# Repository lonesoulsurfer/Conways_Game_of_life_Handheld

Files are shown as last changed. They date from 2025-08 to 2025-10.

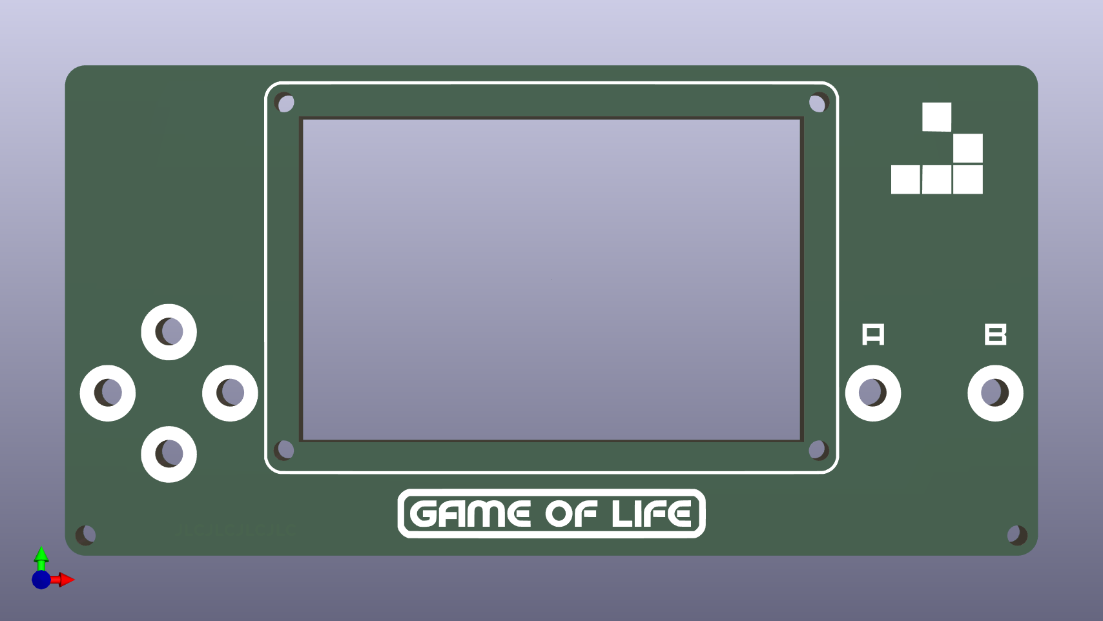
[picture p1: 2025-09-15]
Game of life - Kicad.png

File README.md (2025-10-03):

OOLO0046        QAZB0208

YouTube Vid
Short - https://youtube.com/shorts/Atr1aoWWVLA

Long - https://youtu.be/dLQRpCf72iw

I’ve been fascinated with Conway’s Game of Life ever since I read ‘The Recursive Universe’ way back in 2012. Since then, I wanted a way that I could play the game just like you would play a Nintendo ‘Game & Watch’ – a pocket-sized version that I could whip out anytime and start to explore & build my own patterns.

Fast-forward to 2025 and that idea has become reality! Arduino AI Assistant has been a massive help in building the code and there is absolutely no way that I could of done it without AI’s assistance. If you haven’t used it before and don’t know much about coding, then I strongly recommend that you give it a try.

So, what is Conway’s Game of Life (or GOL for short!). I recently gave the below description in another GOL project which might help those that haven’t heard of it before:

The Game of Life is a cellular automation created by mathematician John Conway. It's what is known as a zero player game, meaning that its evolution and game play is determined by its initial state and requires no further input. You interact with the Game of Life by creating an initial configuration and observing how it evolves.

The game itself is based on a few, simple, mathematical rules consisting of a grid of cells that can either live, die or multiply. When the game is run, the cells can give the illusion that they are alive which is what makes this game so interesting.
Now you know what it is – what does my hand held game version do?

Core Game

• Cellular Automaton: Simulates Conway's famous "zero-player game" where cells live/die based on neighbor count 
• Displayed on a 128x64 OLED screen 
• Toroidal World: Edges wrap around (top connects to bottom, left to right)

5 Game Modes (4 & 5 added in V2)
1. Random Game: Starts with random cell pattern, auto-resets when pattern dies/repeats
2. Custom Builder: Interactive editor to design your own starting patterns
3. Preset Patterns: 5 famous Conway patterns including Gosper Glider Gun
4. Custom Game: Build your own pattern with cursor, long-press SET to start
5. Alt Games: Alternative cellular automata collection
   
     • Brian's Brain: 3-state automaton with birth/dying/dead phases
   
     • Day & Night: Inverse Conway rules creating dense stable patterns
   
     • Seeds: Birth-only automaton creating explosive wave patterns
   
     • Langton's Ant: Single ant creating emergent highway patterns

Controls (5-button resistor ladder)

• Menu Navigation: UP/DOWN navigate, SET selects, LEFT goes back 
• Pattern Editor: Arrow keys move cursor, SET toggles cells, long-press SET starts simulation 
• During Simulation: UP/DOWN changes speed (12 levels), LEFT/RIGHT generates new random

Features

• Real-time Statistics: Generation counter, live cell count, max cells reached 
• Smart Detection: Automatically detects when patterns die out or start repeating 
• Game Over Screen: Shows final statistics for 4 seconds 
• Battery Optimized: Efficient bit-manipulation algorithms 
• Menu System: Clean interface with pattern submenu

Heres some more ideas to implement:

Pattern Management

• Pattern Save/Load: Store custom patterns in EEPROM with names 

• Pattern Library: More famous patterns (pulsar, pentadecathlon, etc.) 

• Random Seeds: Different randomization algorithms (sparse, dense, clusters) 

• Symmetrical Patterns: Generate symmetric starting conditions

Game Modes

• Survival Mode: Try to keep population above threshold for X generations 

• Target Mode: Reach specific cell count goals 

• Time Challenge: Fastest to stabilization 

• Multi-Rule Mode: Different cellular automaton rules (B36/S23, etc.)

Advanced Controls

• Step Mode: Advance one generation at a time with button press 

• Rewind: Store last N generations for backward stepping 

• Pause/Resume: Freeze simulation mid-run 

• Bookmark Positions: Mark interesting generations to return to

Statistics & Analysis

• Population Oscillation Detection: Identify period-N oscillators 

• Stability Analysis: Time to stabilization metrics 

• High Score System: Longest-lived patterns, highest populations 

• Pattern Classification: Auto-detect gliders, oscillators, still lifes

Hardware Enhancements

• Sound Effects: Beeps for births/deaths, musical tones for populations 

 • Color Coding: Different colors for cell age or generation born

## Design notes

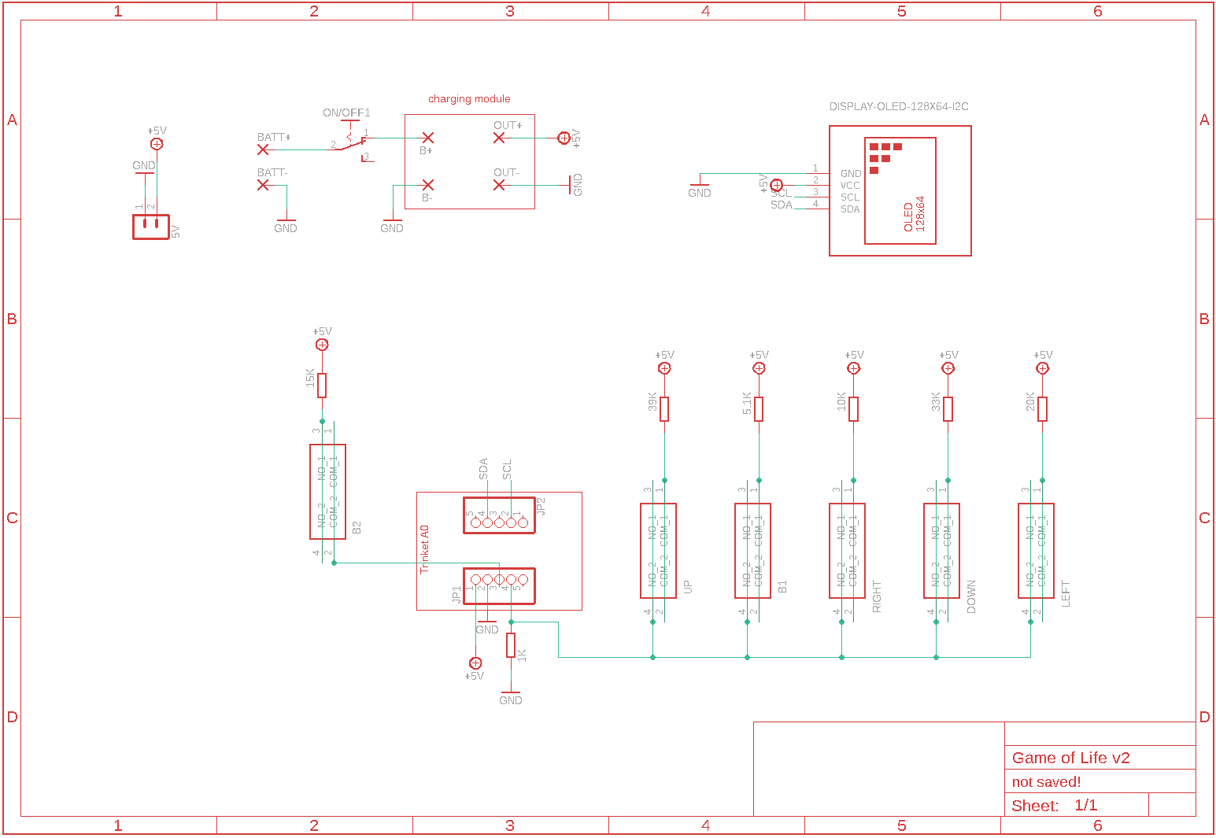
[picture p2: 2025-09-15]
Schematic.png

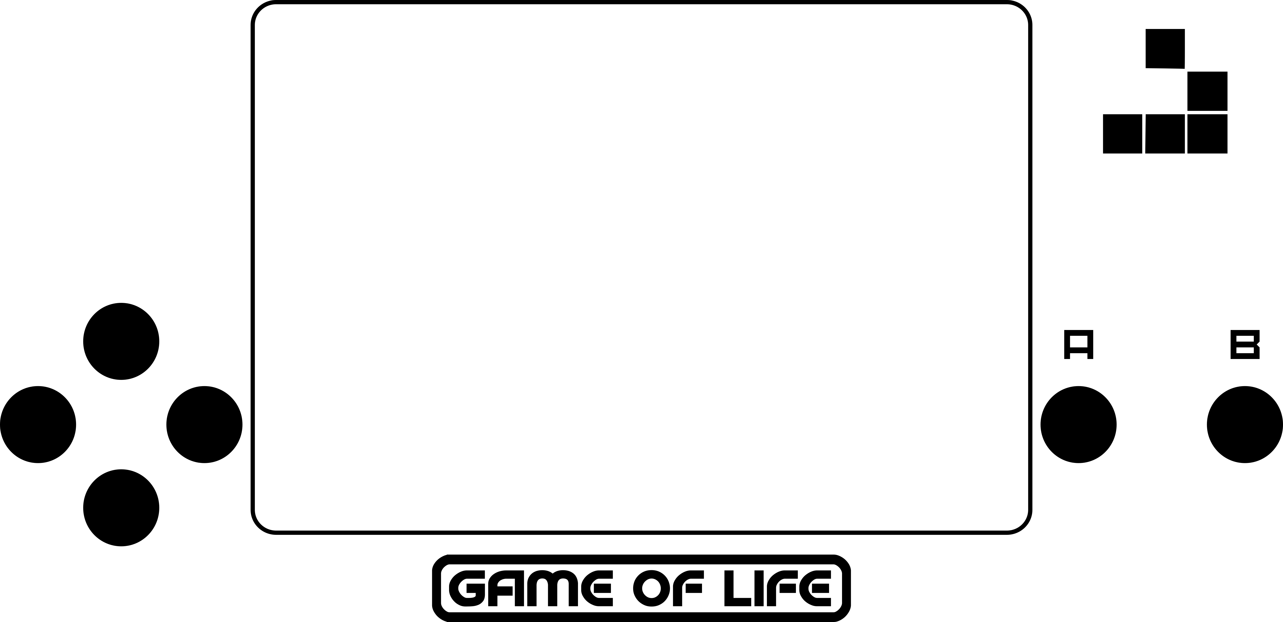
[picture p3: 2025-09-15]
Game of Life - Front Panel Design/Game of Life - Front Panel.png

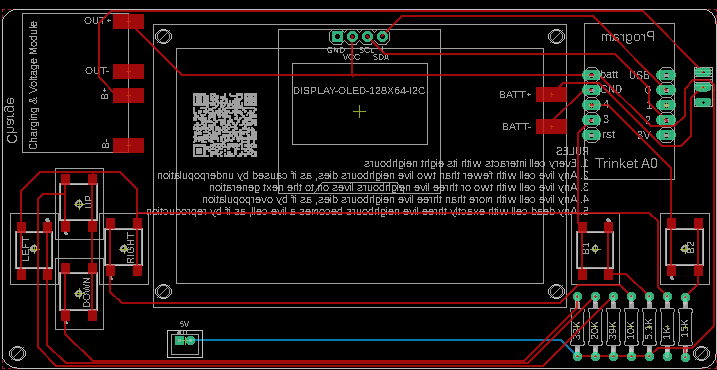
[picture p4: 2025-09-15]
PCB.png

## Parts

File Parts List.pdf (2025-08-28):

Part | Part Number | Type Value | Qty | Link | Image | Notes
Adafruit Trinket M0 | LLC 3500 | 3V version | 1 | Ali Express (https://www.aliexpress.com/w/wholesale-trinket-M0.html?spm=a2g0o.detail.search.0) | | These are availiable from a few different places so check Google for your closest stockist
Charging & voltage step-up module | LX-LCBST | | 1 | Ali Express (https://www.aliexpress.com/item/1005005656423941.html?srcSns=sns_More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)
OLED Screen - 2.42 inch | SSD1309 | | 1 | Ali Express (https://www.aliexpress.com/w/wholesale-oled-2.42.html?spm=a2g0o.detail.search.0)
Resistors | | 1K 5.1K 10K Metal film 15K 20K 33K 39K | 1 1 1 1 1 1 1 | Ali Express (https://www.aliexpress.com/w/wholesale-resistor-metal-film.html?spm=a2g0o.productlist.search.0)
Battery | EB425161LU | Samsung mobile phone battery | | Ali Express (https://www.aliexpress.com/w/wholesale-EB425161LU.html?spm=a2g0o.productlist.search.0)
Tactile Switch | | SMD 11mm | 6 | Ali Express (https://www.aliexpress.com/item/1005007076344493.html?srcSns=sns_More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)
On/Off Switch | MSK-12D19 | Horizontal slide | 1 | Ali Express (https://www.aliexpress.com/item/32828124825.html?srcSns=sns_More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)

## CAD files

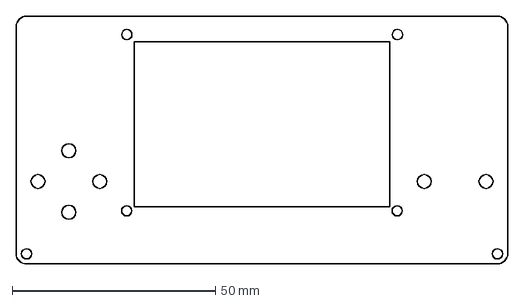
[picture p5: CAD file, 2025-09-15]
Game of Life - Front Panel Design/Game of Life - Fusion.dxf
120.9 x 61.0 mm

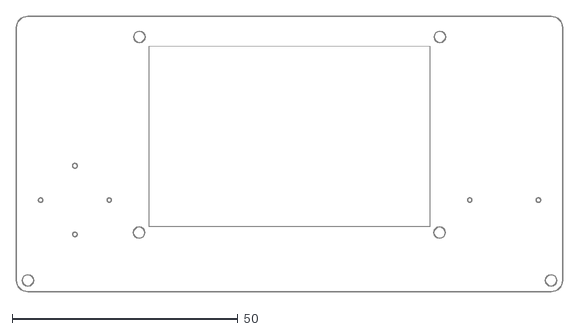
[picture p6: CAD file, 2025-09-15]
Game of Life - Front Panel Design/Game of Life - PCB.dxf
120.9 x 60.9

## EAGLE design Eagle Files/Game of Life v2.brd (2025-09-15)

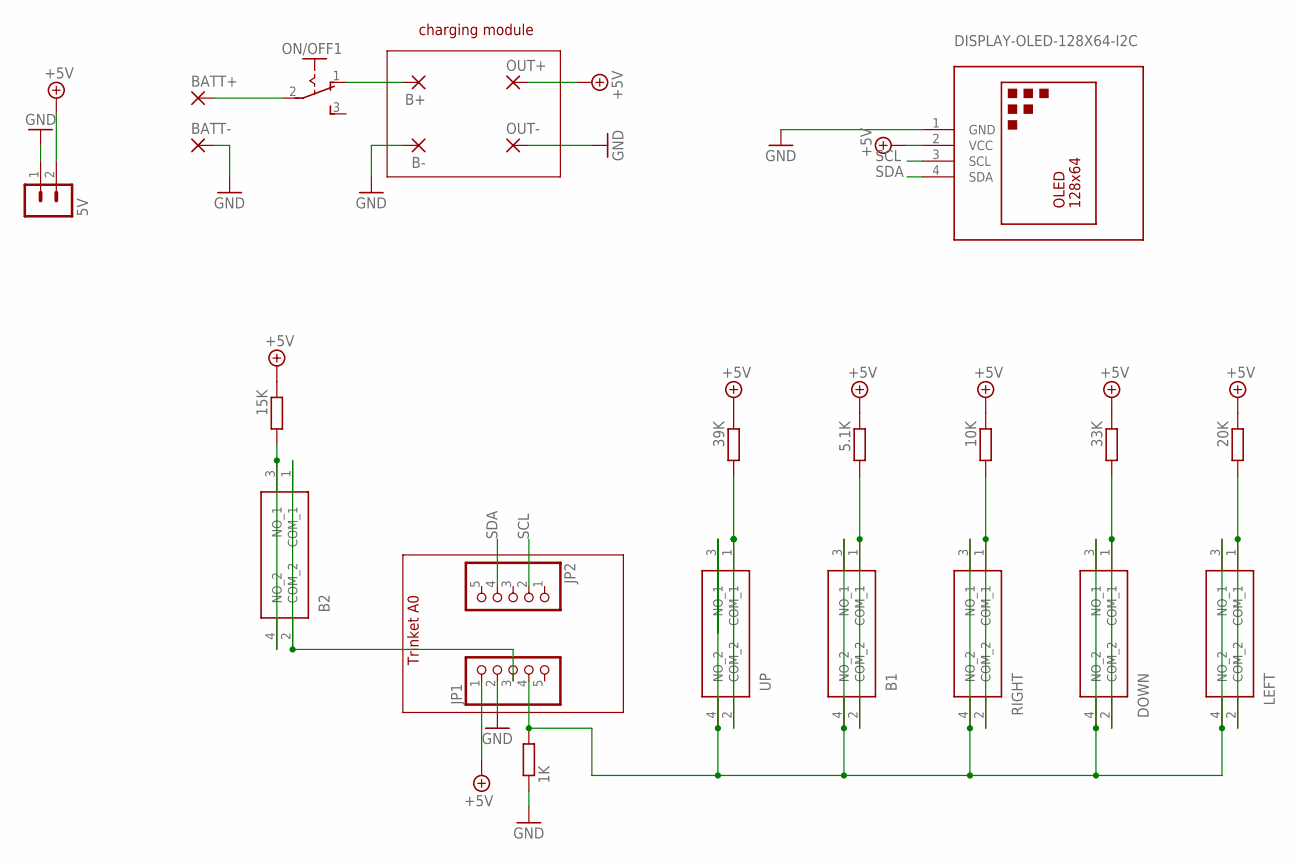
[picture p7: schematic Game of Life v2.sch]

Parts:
5V: B2B-PH-K-S
B1, B2: 101-0364-EV; 1010364EV
B+: SMD5; SMD2,54-5,08
B-: SMD5; SMD2,54-5,08
BATT+: SMD5; SMD2,54-5,08
BATT-: SMD5; SMD2,54-5,08
DOWN: 101-0364-EV; 1010364EV
JP1, JP2: PINHD-1X5; 1X05
LEFT: 101-0364-EV; 1010364EV
ON/OFF1: M251
OUT+: SMD5; SMD2,54-5,08
OUT-: SMD5; SMD2,54-5,08
R1: 1K; 0207/10
R2: 20K; 0207/10
R3: 39K; 0207/10
R4: 10K; 0207/10
R5: 33K; 0207/10
R6: 5.1K; 0207/10
R7: 15K; 0207/10
RIGHT: 101-0364-EV; 1010364EV
U$2: DISPLAY-OLED-128X64-I2C
UP: 101-0364-EV; 1010364EV

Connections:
+5V: 5V.2, JP1.1, OUT+.1, R2.1, R3.1, R4.1, R5.1, R6.1, R7.1, U$2.2 (VCC)
GND: 5V.1, B-.1, BATT-.1, JP1.2, OUT-.1, R1.1, U$2.1 (GND)
unnamed: DOWN.1 (COM_1), DOWN.2 (COM_2), R5.2
unnamed: R3.2, UP.1 (COM_1), UP.2 (COM_2)
unnamed: R4.2, RIGHT.1 (COM_1), RIGHT.2 (COM_2)
unnamed: B1.3 (NO_1), B1.4 (NO_2), DOWN.3 (NO_1), DOWN.4 (NO_2), JP1.4, LEFT.3 (NO_1), LEFT.4 (NO_2), R1.2, RIGHT.3 (NO_1), RIGHT.4 (NO_2), UP.3 (NO_1), UP.4 (NO_2)
unnamed: LEFT.1 (COM_1), LEFT.2 (COM_2), R2.2
unnamed: B1.1 (COM_1), B1.2 (COM_2), R6.2
unnamed: B2.1 (COM_1), B2.2 (COM_2), JP1.3
unnamed: BATT+.1, ON/OFF1.2
unnamed: B+.1, ON/OFF1.1 (O)
unnamed: B2.3 (NO_1), B2.4 (NO_2), R7.2
SCL: JP2.2, U$2.3 (SCL)
SDA: JP2.4, U$2.4 (SDA)

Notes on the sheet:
Trinket A0
charging module

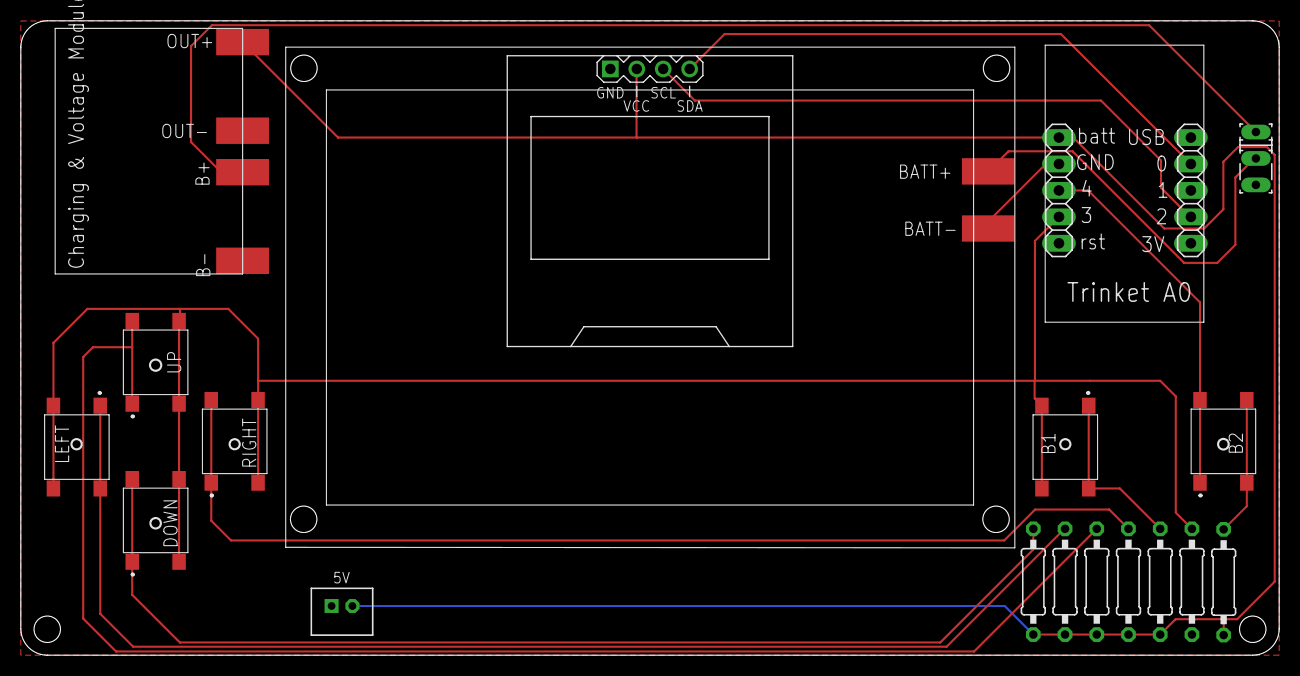
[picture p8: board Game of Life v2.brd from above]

Board: 2 copper layers, 120.9 x 60.9 mm, 24 parts (0 on the bottom side), 14 nets.

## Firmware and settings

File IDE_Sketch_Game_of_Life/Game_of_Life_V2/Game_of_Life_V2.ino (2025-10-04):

/*
 * =====================================================================
 *                    CONWAY'S GAME OF LIFE
 *                     Arduino Implementation
 * =====================================================================
 * 
 * A complete implementation of John Conway's famous cellular automaton
 * "Game of Life" for Arduino microcontrollers with SSD1306 OLED display.
 * 
 * FEATURES:
 * • Five game modes: Random generation, Custom builder, Preset patterns, Symmetric patterns, Alt Games
 * • 12 speed levels with real-time speed control
 * • 5 famous Conway patterns + Symmetric pattern generator
 * • 4 Alternative cellular automata: Brian's Brain, Day & Night, Seeds, Langton's Ant
 * • Interactive pattern editor with blinking cursor
 * • Game statistics tracking (generations, max cells)
 * • Comprehensive menu system with multiple submenus
 * • Automatic pattern detection and game reset
 * • Battery-optimized resistor ladder button input
 * 
 * HARDWARE REQUIREMENTS:
 * • Arduino-compatible microcontroller (tested on Trinket M0)
 * • SSD1306 128x64 OLED display (I2C)
 * • 5-button resistor ladder on analog pin A3
 * • Optional: Button B on analog pin A4 (menu return)
 * 
 * BUTTON MAPPING (Resistor Ladder on A3):
 * • UP: ~39kΩ to 5V    (Navigation/Cursor up/Speed up)
 * • DOWN: ~33kΩ to 5V  (Navigation/Cursor down/Speed down) 
 * • LEFT: ~20kΩ to 5V  (Cursor left/New random/Back in menu)
 * • RIGHT: ~10kΩ to 5V (Cursor right/New random)
 * • SET: ~5.1kΩ to 5V  (Select/Toggle cell/Start simulation)
 * • B: ~15kΩ to 5V   (Return to main menu from anywhere)
 * 
 * GAME MODES:
 * 1. Preset Patterns: Choose from 5 famous Conway patterns
 * 2. Random Game: Starts with random cell pattern, auto-resets on death
 * 3. Symmetric Game: Generate symmetric patterns (Small/Medium/Large)
 * 4. Custom Game: Build your own pattern with cursor, long-press SET to start
 * 5. Alt Games: Alternative cellular automata collection
 *    • Brian's Brain: 3-state automaton with birth/dying/dead phases
 *    • Day & Night: Inverse Conway rules creating dense stable patterns
 *    • Seeds: Birth-only automaton creating explosive wave patterns
 *    • Langton's Ant: Single ant creating emergent highway patterns
 * 
 * CONTROLS:
 * • Menu: UP/DOWN navigate, SET selects, LEFT goes back in submenu
 * • Edit: Arrow keys move cursor, SET toggles cell, long-press SET starts
 * • Simulation: UP/DOWN changes speed, LEFT/RIGHT generates new random
 * • Any mode: Button B returns to main menu
 * • SYMMETRIC PATTERNS: 3 symmetry types (Vertical, Horizontal, 4-way Rotational)
 * 
 * DISPLAY:
 * • 64x32 cell grid displayed at 2x scale on 128x64 OLED
 * • Real-time generation counter and cell statistics
 * • Blinking cursor in edit mode
 * • Automatic game over detection and statistics display
 * • Game-specific visual indicators (ant position, dying cells, etc.)
 * 
 * ALGORITHM:
 * • Optimized bit-manipulation implementation
 * • Toroidal (wraparound) boundary conditions
 * • Hash-based pattern repetition detection
 * • Efficient neighbor counting using lookup table
 * • Game-specific rule engines for each cellular automaton
 * 
 * AUTHOR: Marcus Dunn
 * VERSION: 2.0
 * DATE: 25/09/2025
 * LICENSE: Open Source - feel free to modify and share
 * 
 * Based on John Conway's "Game of Life" cellular automaton (1970)
 * Additional automata: Brian's Brain (1984), Day & Night, Seeds, Langton's Ant (1986)
 * 
 * =====================================================================
 */

#pragma message (" game_of_life_V2 " 25/9/2025 " ")
#include <stdint.h>
#include <limits.h>
#include <stdlib.h>

#include <Wire.h>
#include <Adafruit_GFX.h>
#include <Adafruit_SSD1306.h>

// --- Constants ---
#define SCREEN_WIDTH 128
#define SCREEN_HEIGHT 64

#define BOARD_WIDTH 64
#define BOARD_HEIGHT 32

#define SCALE 2

#define I2C_ADDR 0x3C

// how often to take a hash
#define SHORT_HASH_INTERVAL 6
#define LONG_HASH_INTERVAL 256

// fraction of 32767 to randomly reset if long hash matches
#define LONG_HASH_THRESHOLD 328

#define DEBOUNCE_MS 50 // Debounce value for button presses

// Button input pin using resistor ladder
#define BUTTON_INPUT_PIN A3

// Button value thresholds for resistor ladder
#define BTN_UP_VAL    38
#define BTN_DOWN_VAL  45
#define BTN_LEFT_VAL  73
#define BTN_RIGHT_VAL 139
#define BTN_SET_VAL   250
#define BTN_UP_TOLERANCE 10
#define BTN_DOWN_TOLERANCE 5
#define BTN_RIGHT_TOLERANCE 20
#define BTN_SET_TOLERANCE 20
#define BTN_LEFT_TOLERANCE 10

#define RAND_LONG() ((rand() << 16) ^ rand())

// --- Global Variables and Objects ---
Adafruit_SSD1306 display(SCREEN_WIDTH, SCREEN_HEIGHT, &Wire, -1);

uint32_t board[BOARD_WIDTH];
uint32_t first_col;
uint32_t this_col;
uint32_t cellCount = 0; // Add cellCount variable declaration
uint32_t last_col;

uint32_t short_check_hash = 0;
uint32_t long_check_hash = 0;
uint32_t generation = 0;
uint32_t start_t = 0;
uint32_t frame_start_t = 0;
uint32_t game_hash = 0;  // Global hash variable for game reset
// Statistics variables
uint32_t max_cellCount = 0;

// Game state variables
bool showingStats = false;
unsigned long statsStartTime = 0;

// Variables for control
unsigned long last_button_press_time = 0;
unsigned long last_button_check_time = 0;
int currentSpeedIndex = 0;
int last_button_value = 0;
bool buttonProcessingInProgress = false;
int cursorX = BOARD_WIDTH / 2;
int cursorY = BOARD_HEIGHT / 2;
bool editMode = true;
bool inMenuMode = true;
int menuSelection = 1; // Default to first option
int currentSymmetryType = 0;   // Track current symmetry type (1-4)
int currentSymmetrySize = 0;   // Track current size (1=Small, 2=Medium, 3=Large)

// Game modes
bool inPatternsSubMenu = false;
int patternSelection = 1; // Default pattern selection
int gameMode = 1; // 1 = Random game, 2 = Build your own
const int frameDelays[] = {500, 400, 300, 250, 200, 150, 100, 75, 50, 40, 30, 25};
const int numSpeeds = sizeof(frameDelays) / sizeof(frameDelays[0]);
int currentBriansBrainSize = 1; // Store the size selection for pattern resets
// Symmetric submenu variables
bool inSymmetricSubMenu = false;
int symmetricSizeSelection = 1; // 1=Small, 2=Medium, 3=Large
bool inAltGamesSubMenu = false;
int altGameSelection = 1; // Default alt game selection
// Seeds submenu variables
bool inSeedsSubMenu = false;
int seedsGameSelection = 1; // 1=Random, 2=Custom
bool buttonJustReleased = false;
unsigned long buttonReleaseTime = 0;
bool seedsWasCustom = false;  // Track if Seeds was started in custom mode

// Brian's Brain game state
bool briansBrainMode = false;
uint32_t briansBrain_dying[BOARD_WIDTH];  // Cells that are dying (will become dead next generation)
bool inBriansBrainSubMenu = false;
int briansBrainSizeSelection = 1;   // 1=Small, 2=Medium, 3=Large, 4=Random, 5=Custom
bool briansBrainWasCustom = false;  
uint32_t briansBrain_hash = 0;          // Hash for pattern detection
uint32_t briansBrain_prev_hash = 0;     // Previous hash for comparison
uint32_t briansBrain_short_hash = 0;    // Short interval hash
int briansBrain_lowCellCounter = 0;     // Count consecutive generations with few cells

// Day & Night game state
bool dayNightMode = false;

// Langton's Ant variables
bool langtonAntMode = false;

// Seeds variables
bool seedsMode = false;
int antX, antY;           // Ant position
int antDirection;         // 0=North, 1=East, 2=South, 3=West
unsigned long lastAntMove = 0;
const unsigned long ANT_MOVE_DELAY = 100; // ms between ant moves

static uint8_t bit_counts[] = {
    0,  // 0
    1,  // 1
    1,  // 2
    2,  // 3
    1,  // 4
    2,  // 5
    2,  // 6
    3   // 7
};

// --- Function Prototypes ---
void randomizeBoard();
void drawCell(int, int, int);
void collectRandomness(int);
void drawTitle();
void resetGame(uint32_t, uint32_t);
static inline uint32_t rotate_shift_three(uint32_t x, int n);
void handleDirectionalButtons();
void handleSetButton();
void handleButtonB();
void flashLED();
void drawCursor();
void clearBoard();
int readButtonValue();
bool isBtnUp(int val);
bool isBtnDown(int val);
bool isBtnLeft(int val);
bool isBtnRight(int val);
bool isBtnSet(int val);
 void showMenu();
void showGameStatistics();
void startShowingStats();
void loadPresetPattern(int patternId);
void generateSymmetricPattern(int symmetryType);
void generateVerticalSymmetric();
void generateHorizontalSymmetric();
void generateRotationalSymmetric();
void generateDiagonalSymmetric();
void generateSmallSymmetricPattern(int symmetryType);
void generateMediumSymmetricPattern(int symmetryType);
void updateDayNight();
void drawDayNight();
void initializeDayNight();
void drawLangtonsAnt();
void initializeLangtonsAnt();
void updateSeeds();
void drawSeeds();
void initializeSeeds();
void updateLangtonsAnt();
  
// --- Button Functions ---
int readButtonValue() {
    return analogRead(BUTTON_INPUT_PIN);
}

bool isBtnUp(int val) {
    return (val >= 38 && val <= 40);
}

bool isBtnDown(int val) {
    return (val >= 44 && val <= 47);
}

bool isBtnLeft(int val) {
    return (val >= 74 && val <= 75);
}

bool isBtnRight(int val) {
    return (val >= 141 && val <= 143);
}

bool isBtnSet(int val) {
    return (val >= 200 && val <= 300);  // Much wider range
}

  bool isBtnB(int val) {
    return (val >= 1020 && val <= 1023);  // Button B threshold
}

// --- Game Functions ---
void toggleCellAtCursor() {
    uint32_t mask = 1UL << cursorY;
    board[cursorX] ^= mask;
}

void drawCursor() {
    bool cellIsLit = (board[cursorX] & (1UL << cursorY)) != 0;
    bool blinkState = (millis() / 300) % 2;  // Slower blink, every 300ms
    
    if (blinkState) {
// Reversed cursor - empty when no cell, lit when cell exists
        int color = cellIsLit ? WHITE : BLACK;
        display.drawPixel(cursorX * SCALE, cursorY * SCALE, color);
        
        // Add a simple border around cursor position
        if (cursorX > 0) display.drawPixel((cursorX-1) * SCALE, cursorY * SCALE, WHITE);
        if (cursorX < BOARD_WIDTH-1) display.drawPixel((cursorX+1) * SCALE, cursorY * SCALE, WHITE);
        if (cursorY > 0) display.drawPixel(cursorX * SCALE, (cursorY-1) * SCALE, WHITE);
        if (cursorY < BOARD_HEIGHT-1) display.drawPixel(cursorX * SCALE, (cursorY+1) * SCALE, WHITE);
    }
}

void randomizeBoard() {
    for (int x = 0; x < BOARD_WIDTH; x++) {
        uint32_t col;
        col = board[x] = RAND_LONG() & RAND_LONG() & RAND_LONG();
    }
}

void drawCell(int x, int y, int c) {
    display.drawPixel(x * SCALE, y * SCALE, c);
}

void collectRandomness(int t) {
    uint32_t wait_t = millis();
    uint32_t r = 0;
    while (wait_t + t > millis()) {
        r += analogRead(A4);
    }
    randomSeed(r);
}
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
    void loop() {
     
    // Check for button presses
    handleDirectionalButtons();
    handleSetButton();
    handleButtonB();

    // Skip game logic if in menu mode
    if (inMenuMode) {
        return;
    }

    if (!editMode) {
        // Game of Life simulation
        unsigned long current_time = millis();
        game_hash = 5381;  // Store in global variable

        // Handle statistics display state
        if (showingStats) {
            // Stay in statistics display for 2 seconds
            if (current_time - statsStartTime >= 2000) {
                showingStats = false;
                display.clearDisplay();
                display.display();
                
                // Return to appropriate menu based on game mode
                if (gameMode == 8 && briansBrainMode) {
                    // Return to Brian's Brain submenu
                    briansBrainMode = false;
                    inMenuMode = true;
                    inBriansBrainSubMenu = true;
                    inAltGamesSubMenu = false;
                    briansBrainSizeSelection = 1;
                    briansBrainWasCustom = false;
                } else {
                    // Return to main menu for other games
                    inMenuMode = true;
                    menuSelection = 1;
                }
                showMenu();
                display.display();
                generation = 0;
                start_t = micros();
            }
            return; // Skip simulation while showing stats
        }
        else if (current_time - frame_start_t >= frameDelays[currentSpeedIndex]) {
            frame_start_t = current_time;

          generation++; // Count generations only when simulation actually advances
            
               switch (gameMode) {
                case 1:
                case 2:
                case 3:
                    // Conway's Game of Life (existing code below)
                    break;
                    
                case 4: // Symmetric Game (keep this for regular symmetric patterns)
                    break;
                    
                case 5: // Day & Night
                    if (dayNightMode) {
                        updateDayNight();
                        drawDayNight();
                        return; // Skip Conway's logic
                    }
                    break;
                    
                case 6: // Seeds
    if (seedsMode) {
        if (editMode) {
            // Custom Seeds - show edit interface
            display.clearDisplay();
            for (int x = 0; x < BOARD_WIDTH; x++) {
                for (int y = 0; y < BOARD_HEIGHT; y++) {
                    if (board[x] & (1UL << y)) {
                        drawCell(x, y, WHITE);
                    }
                }
            }
            drawCursor();
            display.display();
            return;
        } else {
            // Running Seeds simulation
            updateSeeds();
            drawSeeds();
            
            // Auto-reset based on original mode
            if (cellCount == 0 || (cellCount > 500 && generation > 150)) {
                if (seedsWasCustom) {
                    // Return to edit mode for custom Seeds
                    clearBoard();
                    editMode = true;
                    cursorX = BOARD_WIDTH / 2;
                    cursorY = BOARD_HEIGHT / 2;
                } else {
                    // Generate new random pattern for random Seeds
                    initializeSeeds();
                }
                generation = 0;
            }
            return;
        }
    }
    break;
                    
                case 7: // Langton's Ant
                    if (langtonAntMode) {
                        updateLangtonsAnt();
                        drawLangtonsAnt();
                        return; // Skip Conway's logic
                    }
                    break;
                    
            case 8: // Brian's Brain
                    if (briansBrainMode) {
                        updateBriansBrain();
                        drawBriansBrain();
                        
                        // Track low cell counts
                        if (cellCount < 10 && generation > 20) {
                            briansBrain_lowCellCounter++;
                            
                            // If cells stay low for 15 consecutive generations, game over
                            if (briansBrain_lowCellCounter >= 15) {
                                startShowingStats();
                                briansBrain_lowCellCounter = 0;  // Reset for next game
                                return;
                            }
                        } else {
                            // Reset counter if cell count goes back up
                            briansBrain_lowCellCounter = 0;
                        }
                        
                        // Also end if completely dead
                        if (cellCount == 0 && generation > 10) {
                            startShowingStats();
                            briansBrain_lowCellCounter = 0;
                            return;
                        }
                        
                        return; // Skip Conway's logic
                    }
                    break;
            }

            
            // Conway's Game of Life logic (only runs for cases 1, 2, 3)
            if (gameMode >= 1 && gameMode <= 3) {
            } else if (dayNightMode) {
                updateDayNight();
                drawDayNight();
                return; // Skip Conway's logic
           }

            cellCount = 0; // Reset cell count before each generation

            // Clear display for Conway's Game of Life
            display.clearDisplay();
            
            for (int x = 0; x < BOARD_WIDTH; x++) {
                uint32_t left;
                if (x == 0) {
                    left = board[BOARD_WIDTH - 1];
                } else {
                    left = board[x - 1];
                }
                uint32_t center = board[x];
                uint32_t right;
                if (x == BOARD_WIDTH - 1) {
                    right = board[0];
                } else {
                    right = board[x + 1];
                }
                this_col = 0;
                uint32_t hash_acc = 0;
                
                for (int y = 0; y < BOARD_HEIGHT; y++) {
                    // Calculate next generation and hash
                    hash_acc <<= 1;
                    uint32_t shift_center = rotate_shift_three(center, y);
                    int count = bit_counts[rotate_shift_three(left, y)] +
                                bit_counts[shift_center] +
                                bit_counts[rotate_shift_three(right, y)];
                    bool alive = shift_center & 0x2;
                    if ((count == 3) || (count == 4 && alive)) {
                        this_col |= 1 << y;
                        hash_acc |= 1; cellCount++;  // Count live cells
                    }
                    if ((y & 0x7) == 0x7) {
                       game_hash = ((game_hash << 5) + game_hash) ^ hash_acc;
                        hash_acc = 0; 
                    }
                }
                
                if (x > 1) {
                    board[x - 1] = last_col;
                    for (int y = 0; y < BOARD_HEIGHT; y++) { 
                        if (last_col & 1) {
                            drawCell(x - 1, y, WHITE);
                        }
                        last_col >>= 1;
                    }
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

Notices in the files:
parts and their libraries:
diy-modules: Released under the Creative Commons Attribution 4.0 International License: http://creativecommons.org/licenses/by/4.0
